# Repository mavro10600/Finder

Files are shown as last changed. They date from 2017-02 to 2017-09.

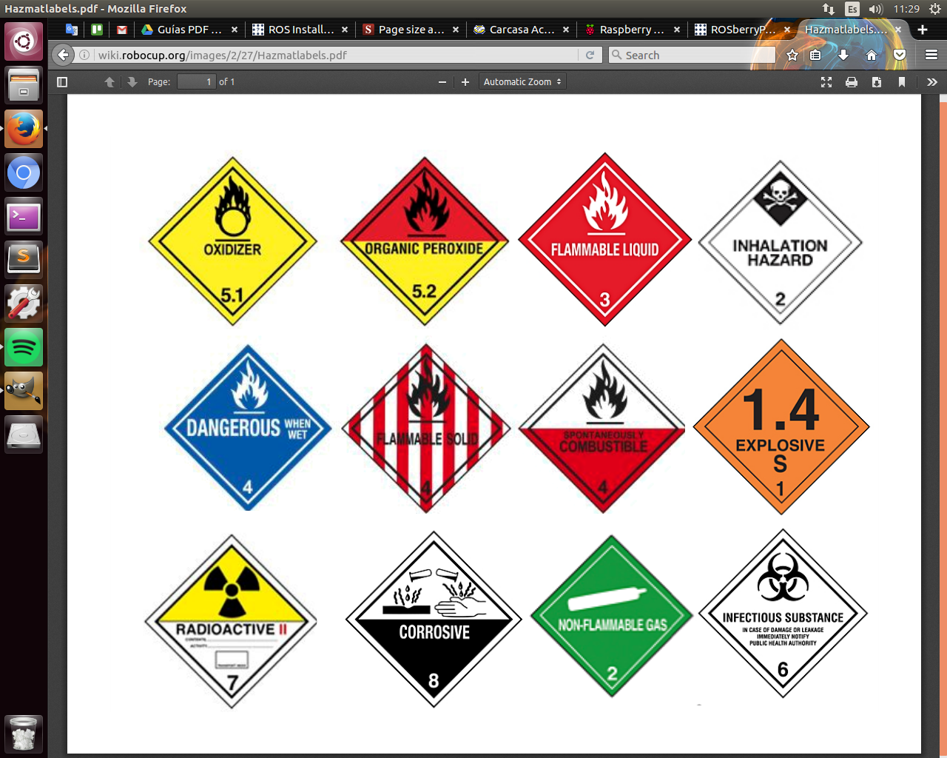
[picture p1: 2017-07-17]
catkin_et/src/vision/labels_hazmate_detector/scripts/hlabel/hazard_labels.png

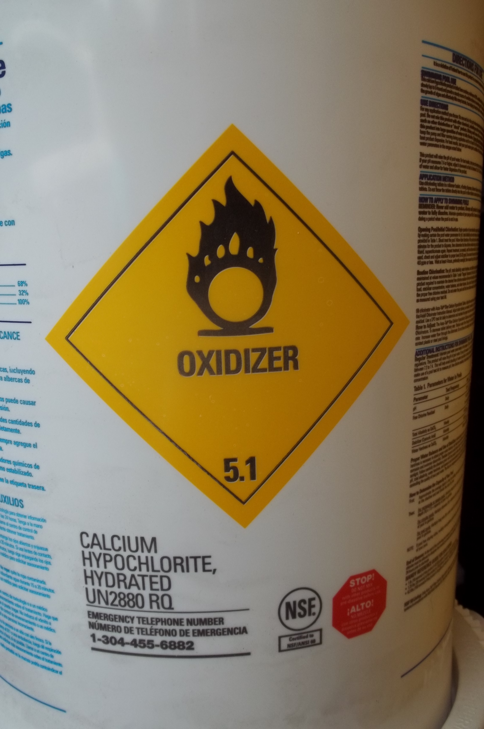
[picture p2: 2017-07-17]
catkin_et/src/vision/labels_hazmate_detector/scripts/hlabel/oxidizerTest1.jpg

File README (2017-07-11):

//
//readme de mavro
//hola
//procedimiento para usar el workspace de ROS:
Primero, en la carpeta build, en el archivo Makefile
cambiamos la ruta de source dir y de binary dir

# The top-level source directory on which CMake was run.
CMAKE_SOURCE_DIR = /home/mavro/Finder/Finder/catkin_et/src

# The top-level build directory on which CMake was run.
CMAKE_BINARY_DIR = /home/mavro/Finder/Finder/catkin_et/build

Luego, vamos a la carpeta catkin_et, y ejecutamos el comando:

$ catkin_make -DCMAKE_BUILD_TYPE=Release

Luego 

$ source ./devel/setup.bash
finder@finder-Dell-System-XPS-15Z:~ .->rosparam set /order "[ 1,2,3,4]"
finder@finder-Dell-System-XPS-15Z:~ .->rosparam set /sentido "[1,0,0,0]"

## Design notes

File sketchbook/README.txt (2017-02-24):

Veamos, faltaaa
Unir los codigos de aqui usando rosserial
entonces, primero usar rosserial para enviar un dato tipo tf, 
luego en la compu
mandar un nodo que lea lo que publica en esa direccion serial el arduino
y lu publique a un jointstate
Entonces lo va  a leer este otro nodo que va a hacer algo con el digamos 
convertirlo a radianes o ago asi
El archivo Position1 Motor test es el mas actual, digamos, en el es con 
arduino mega y veamos, si se utiliza con rosserial para enviar el estado
de la junta, veamos entonces eso es lo que quiero lograr.

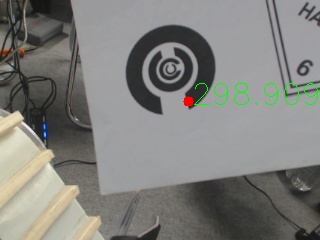
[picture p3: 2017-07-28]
catkin_et/src/roswww/www/img/temp/cPatternDetected5.21694941916.jpg

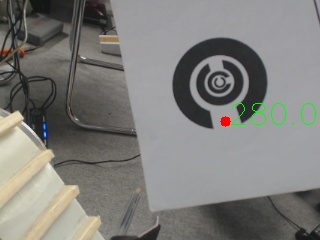
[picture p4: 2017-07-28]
catkin_et/src/roswww/www/img/temp/cPatternDetected4.88778320093.jpg

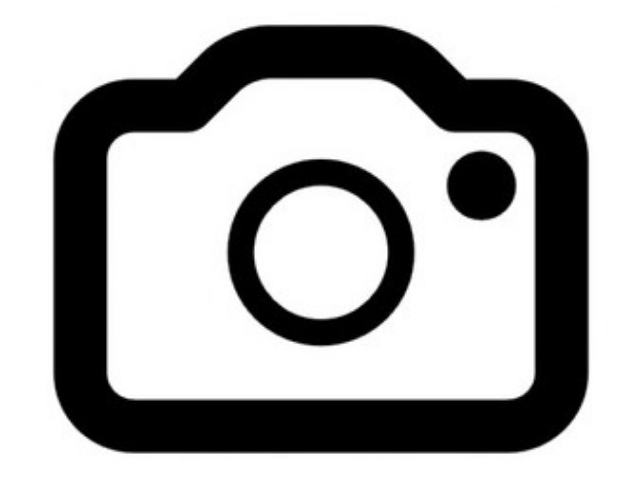
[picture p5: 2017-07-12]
catkin_et/src/roswww/www/img/camera.jpg

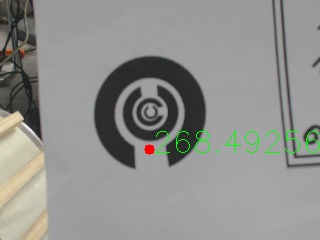
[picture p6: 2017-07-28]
catkin_et/src/roswww/www/img/temp/cPatternDetected4.68607926313.jpg

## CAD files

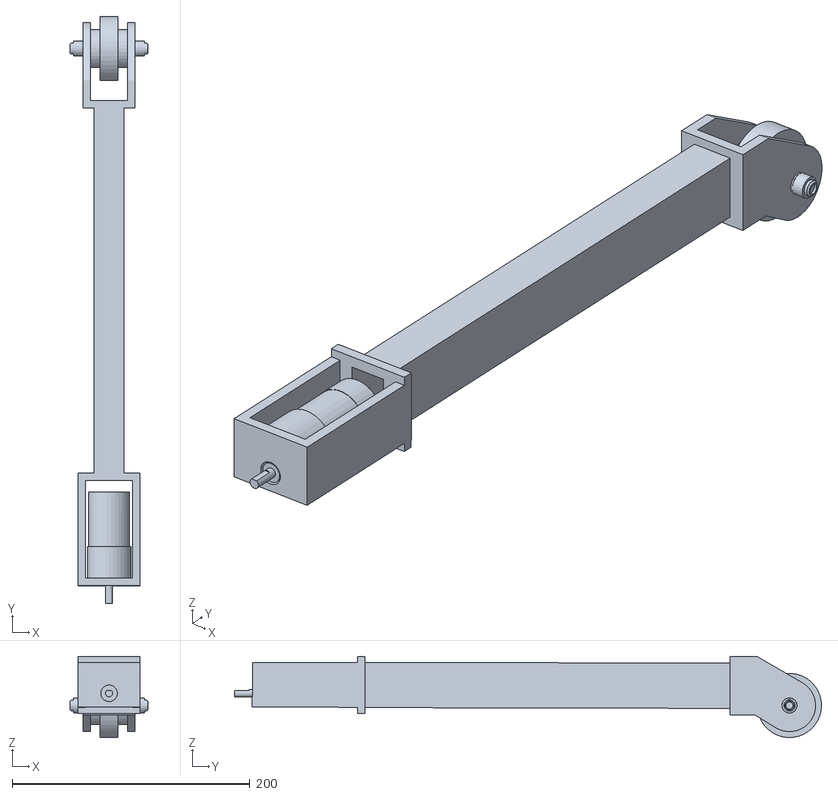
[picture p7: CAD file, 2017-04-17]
catkin_et/src/config_files/meshes/codo.stl
65.7 x 494.1 x 68.3

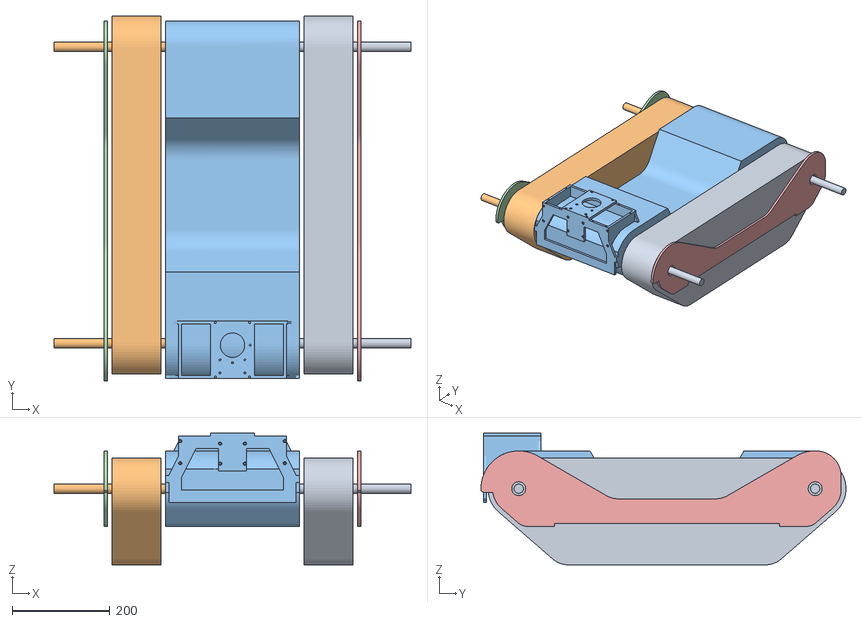
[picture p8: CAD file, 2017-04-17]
catkin_et/src/finder_description/chasis.obj
727.8 x 745.0 x 269.1

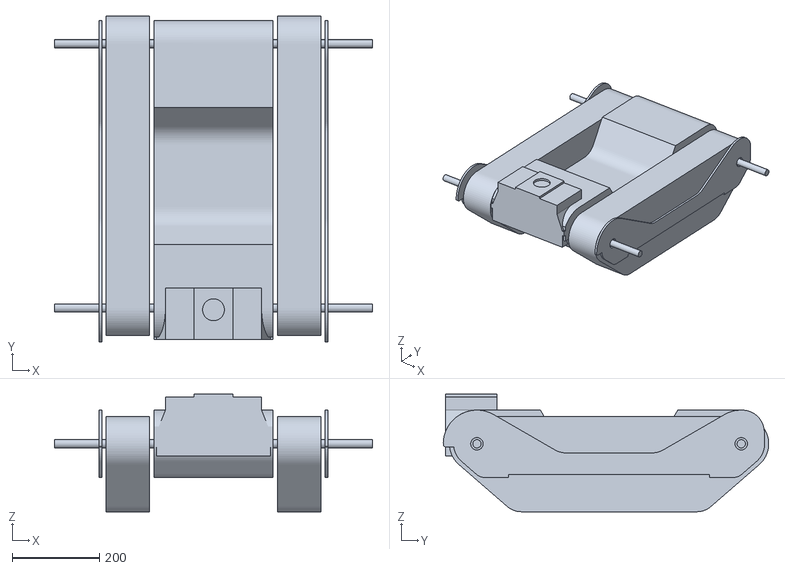
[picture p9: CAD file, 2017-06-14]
catkin_et/src/finder_description/mallas/chasis.stl
727.8 x 745.0 x 269.1

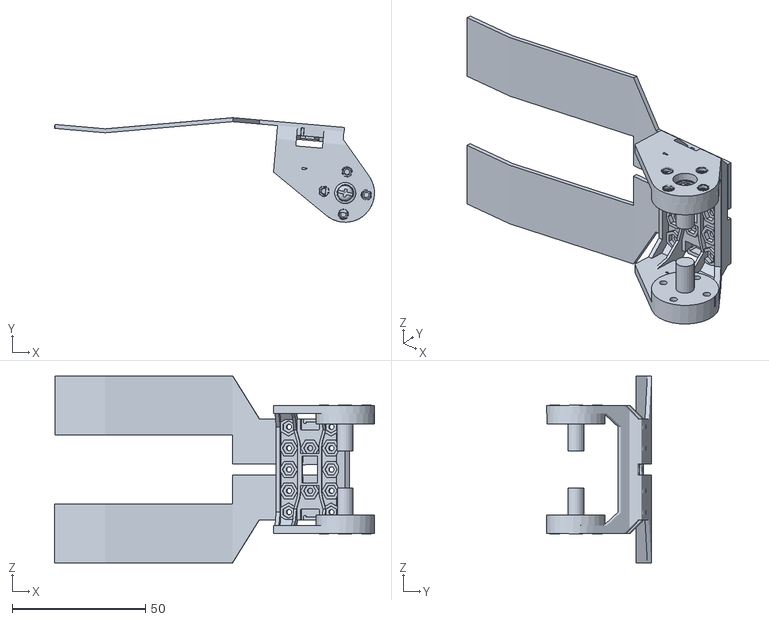
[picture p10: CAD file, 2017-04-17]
catkin_et/src/finder_description/meshes/fingers_finder_arm_l.obj
120.1 x 39.3 x 70.0

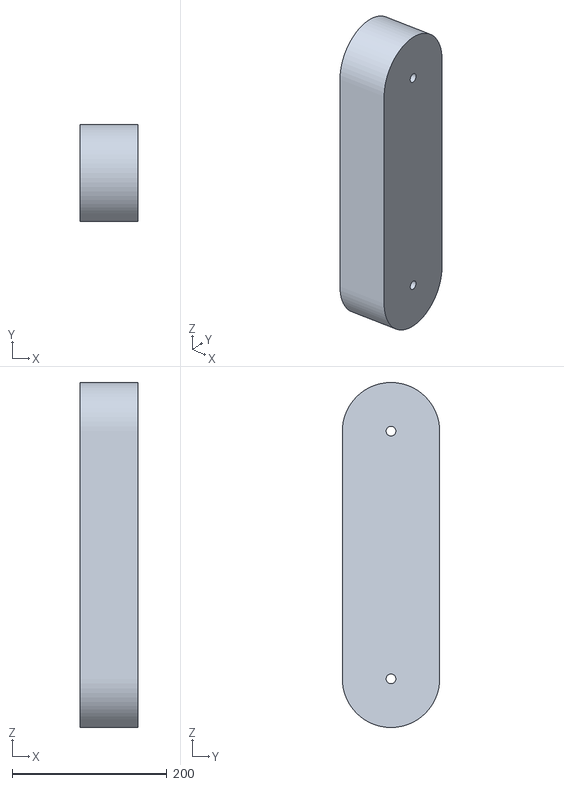
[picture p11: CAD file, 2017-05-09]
catkin_et/src/finder_description/meshes_light/brazo_izq_trasero.stl
75.0 x 125.9 x 445.9

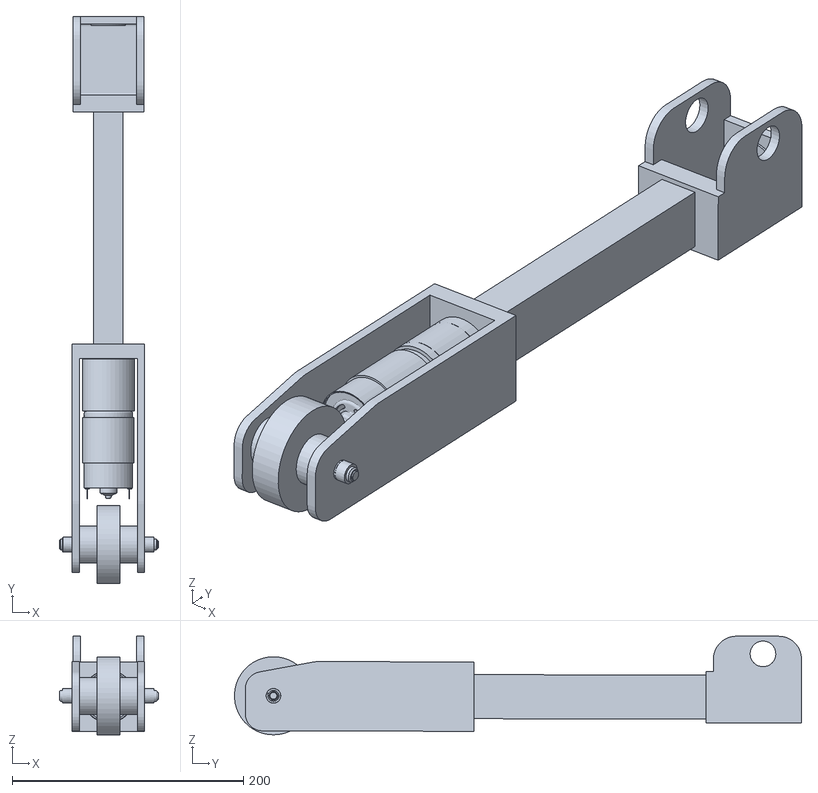
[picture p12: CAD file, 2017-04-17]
catkin_et/src/config_files/meshes/hombro.stl
85.7 x 490.0 x 85.3

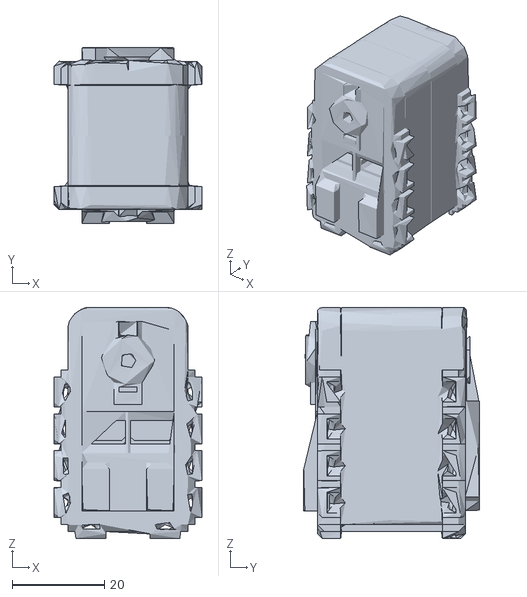
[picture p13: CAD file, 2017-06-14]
catkin_et/src/finder_description/mallas/ax12_box.stl
32.0 x 38.0 x 50.0

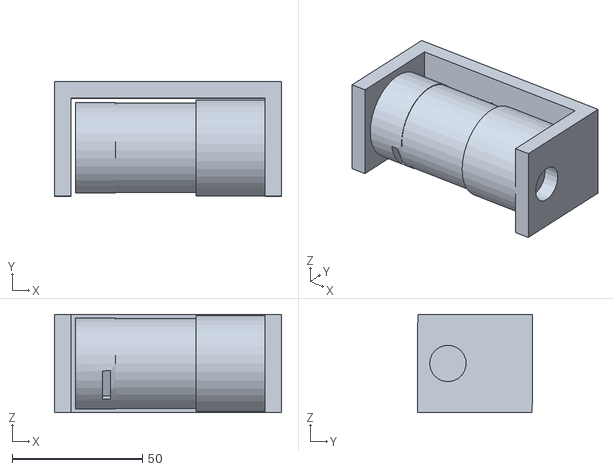
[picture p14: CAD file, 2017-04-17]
catkin_et/src/finder_description/meshes_2/roll1.obj
87.0 x 44.0 x 37.7

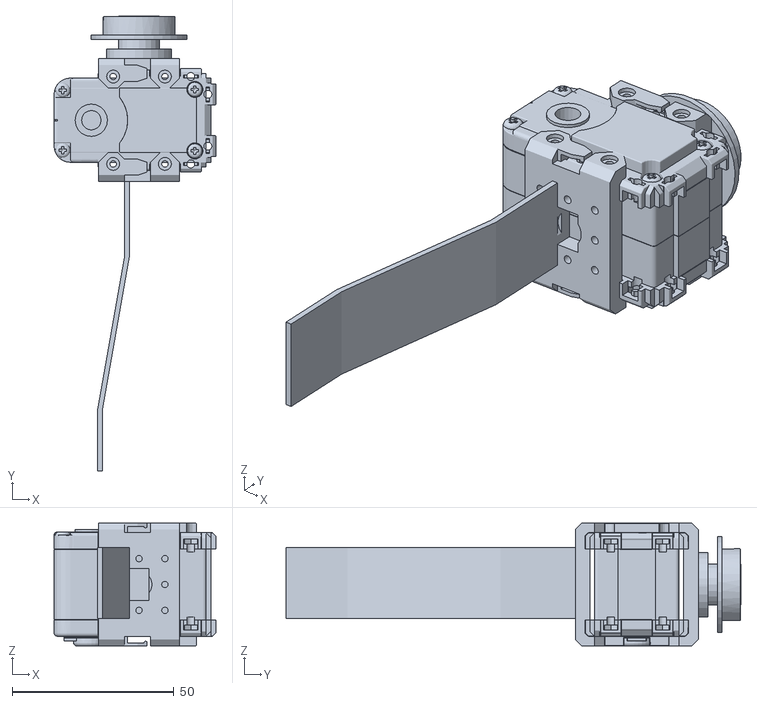
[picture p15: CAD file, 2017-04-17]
catkin_et/src/config_files/meshes/yaw_finder_arm_.obj
50.0 x 140.6 x 38.0

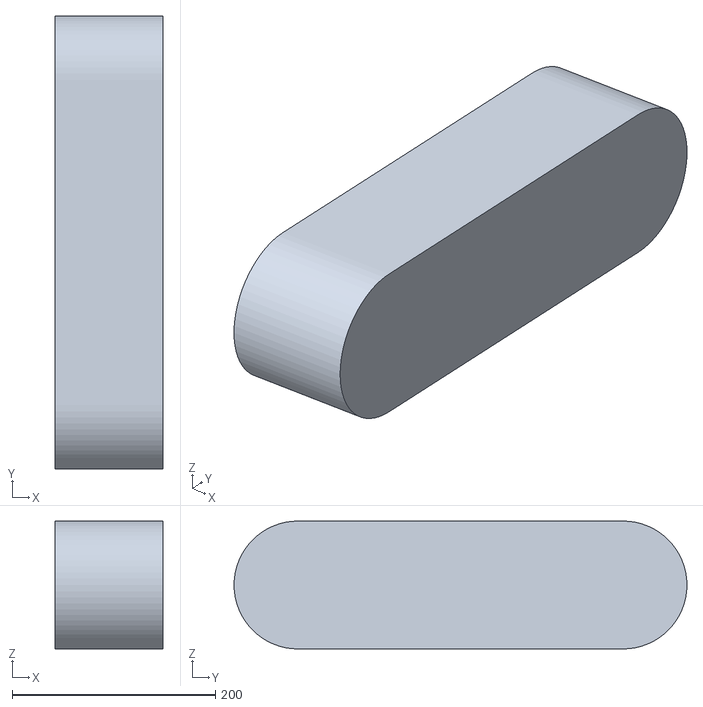
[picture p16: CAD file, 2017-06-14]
catkin_et/src/finder_description/mallas/brazo_auxiliar_simple.stl
106.6 x 445.9 x 125.9

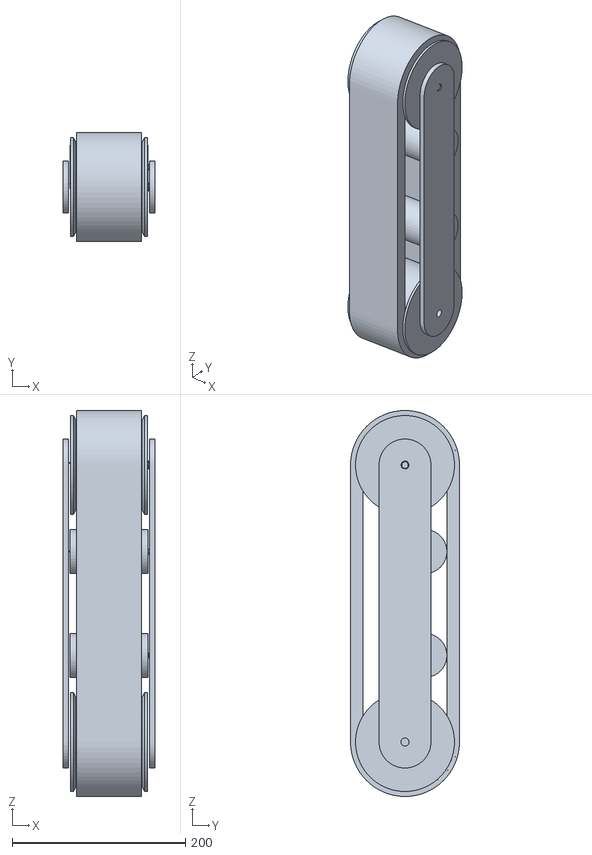
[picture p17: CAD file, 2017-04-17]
catkin_et/src/finder_description/meshes_2/flipper_lb.obj
106.6 x 125.9 x 445.9

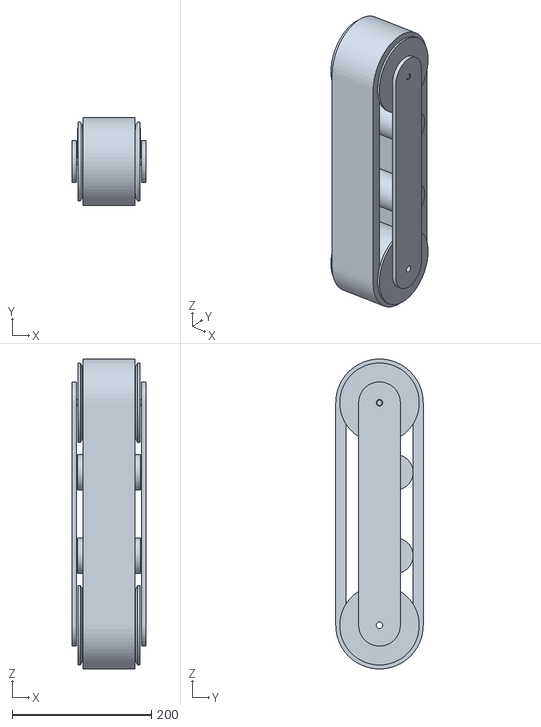
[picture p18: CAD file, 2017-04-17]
catkin_et/src/config_files/meshes/brazo_der_trasero_v2.stl
106.6 x 125.9 x 445.9

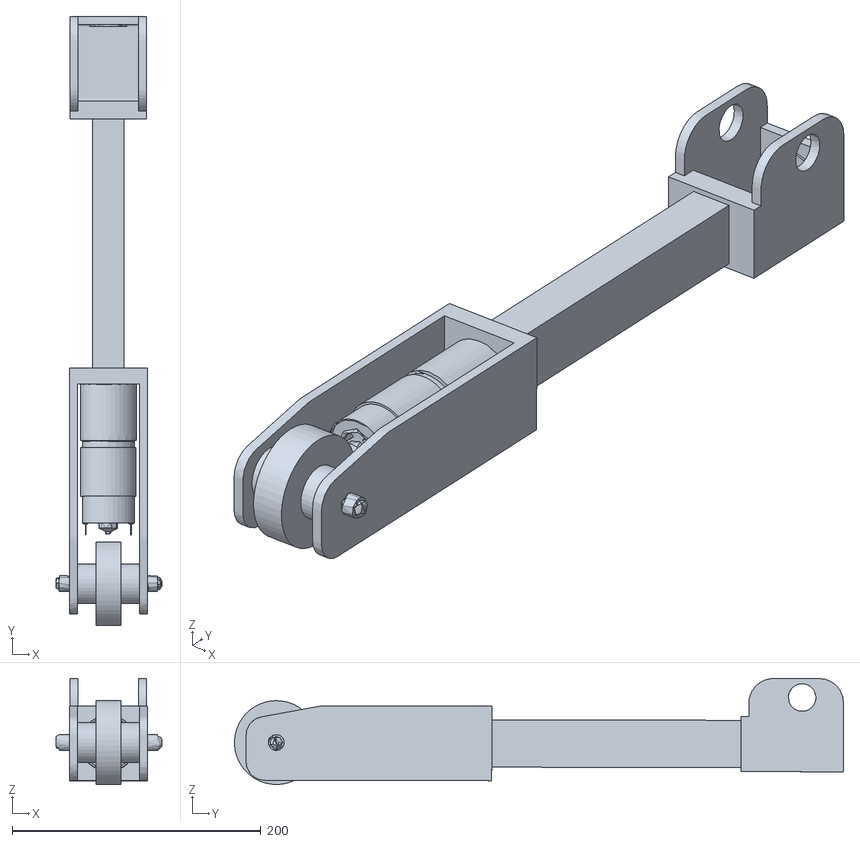
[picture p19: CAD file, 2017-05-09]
catkin_et/src/finder_description/mallas/hombro.obj
85.6 x 490.0 x 85.3

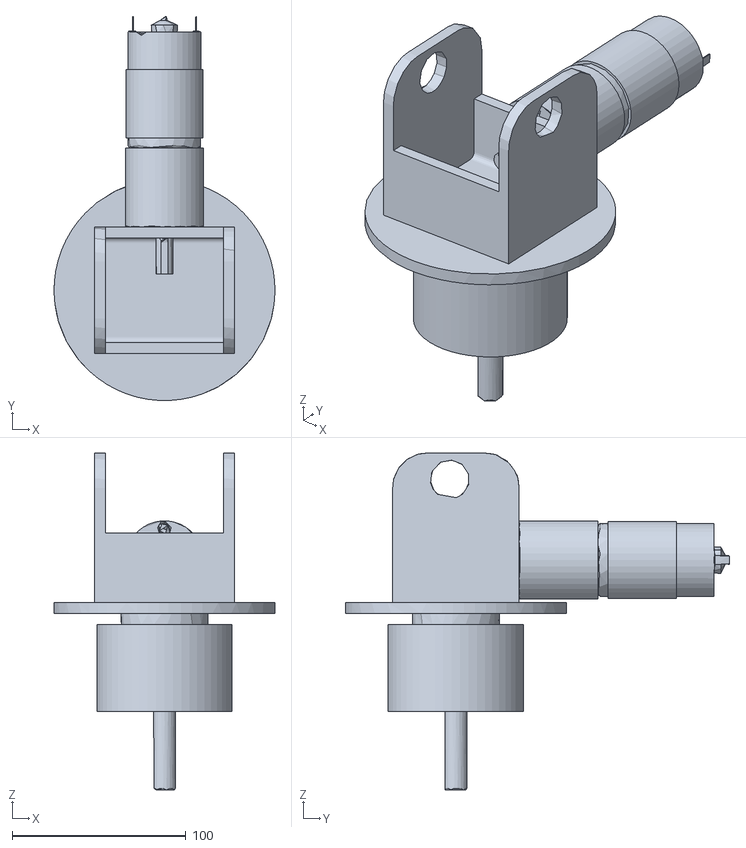
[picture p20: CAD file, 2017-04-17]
catkin_et/src/finder_description/meshes_2/base.obj
127.0 x 220.8 x 193.7

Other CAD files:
catkin_et/src/finder_description/meshes_2/fingers.obj
catkin_et/src/finder_description/meshes_light/brazo_der_frontal.stl
catkin_et/src/finder_description/meshes_light/brazo_der_trasero.stl
catkin_et/src/finder_description/meshes_light/brazo_izq_frontal.stl
catkin_et/src/config_files/meshes/base.obj
catkin_et/src/config_files/meshes/base.stl
catkin_et/src/config_files/meshes/brazo_der_frontal_v2.obj
catkin_et/src/config_files/meshes/brazo_der_frontal_v2.stl
catkin_et/src/config_files/meshes/brazo_der_trasero_v2.obj
catkin_et/src/config_files/meshes/brazo_izq_frontal_v2.obj
catkin_et/src/config_files/meshes/brazo_izq_frontal_v2.stl
catkin_et/src/config_files/meshes/brazo_izq_trasero_v2.obj
catkin_et/src/config_files/meshes/brazo_izq_trasero_v2.stl
catkin_et/src/config_files/meshes/chasis.obj
catkin_et/src/config_files/meshes/codo.obj
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

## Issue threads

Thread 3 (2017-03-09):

Como usar con ros el programa prueba roboclaw 1tarjeta

mavro10600, 2017-03-09:
Bien,  primero que nada, me parece que esta funcionando para roll y pitch. El objeto asociado es rc,conectado al serial3 de la stellaris, la velocidad de comunicación creo que esta en 115200,  si su roboclaw no esta a esa velocidad no va a pasar nada,  si presionas mode y parpadea creo 8 veces es que esta en packet serial y el address es 80, presionas lipo un par de segundos y sales,  luego presionas set y si parpadea 4veces la velocidad es de 38400,presinas dos veces set para avanzar a 115200,  el caso es que parpadee 6 veces.  Conectas s1 y s2 a pd6 y pd7 me parece,si no los volteas,  descubrí que el conversor de niveles no es necesario.  Y luego,  en tu laptop,  lanzas roscore y luego rosrun rosserial-python serial_node. Py /dev/ttyACM0, o puedes laanzar mas explicito como argumentos_port:=/dev/ttyACM0_baud:=57600 o algo asi,  no recuerdo bien al valor del baudaje.
Y mmm si lanzas rostopic list deben aparecer los topicos que lanza y recibe la stellaris, shoulder_out y shoulder por ejemplo,  el primero es el valor a enviar para controlar el motoor del hombro y shoukder es el valor del encoder asociado.  Puedes escribir rostopic echo /shoulder oara ver el valor del encoder,  y rostopic pub /shoulder_out std_msgs/Int16 70 para mandar que se mueva el motor.  Entonces,  en el codigo de la stellaris,  tienes el objeto rc,  asociado a la rovoclaw conectada a los pines del serial3,  en la función setup encoders llamamos la instrucción setencodermode y el argumento es 0 para que funcione como encoder de cuadratura,  si enviamos un 129 funciona como encoder analógica.  Luego en la funcion update motors,  llamo la funcion rc. forwardbackwardM1 (address, roll_out)  donde 64 es paro,  0 es toda la velocidad. Hacia un lado y 128 para el otro lado,  asi qie lo que publiques al topico en ros desde tu lap,  procura que este entre esos valores,  asimismo en el programa,  inicio en valor de roll_ouyt=64

Closed 2017-05-02.

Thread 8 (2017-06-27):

Subir codigo de la stellaris de sensores

mavro10600, 2017-06-27:
Cesar, sube el codigo de tu stellaris y agrega pines para que lean los sensores de corriente, tambien juntar el codigo de eli para controlar los leds de potencia y el termografo

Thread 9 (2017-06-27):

hacer rutina de finales de carrera

mavro10600, 2017-06-27:
hacer pines de finles de carrera y el nodo de begginers tutorials/ scripts/base_launchpad.py para que reconozca un Reset enviado por la stellaris. asimismo en le programa de brazo stellaris launchpad poner la rutina que apague el motor y envie cero en dicho motor asi como el mensaje de status de finales de carrera

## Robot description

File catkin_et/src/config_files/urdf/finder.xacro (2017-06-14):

<?xml version="1.0"?>
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
<robot name="finder" xmlns:xacro="http://www.ros.org/wiki/xacro">

	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
    <xacro:macro name="default_geometry" params="cad_dir:=package://config_files/meshes cad_file extension:=obj">
        <geometry>
	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
        </geometry>
    </xacro:macro>

	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
	<xacro:property name="pi" value = "3.14159265359"/>
	<property name="deg_to_rad" value="0.01745329251994329577"/>

	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
   	<xacro:macro name="inertial_matrix" params="mass">
    	<inertial>
      		<mass value="${mass}"/>
        	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
  		</inertial>
   </xacro:macro>

	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
	<xacro:macro name = "lateral_arms" params="name cad_name origin">
		<link name = "${name}">
			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
	</link>
	</xacro:macro>
	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
	<xacro:macro name = "arms_joints" params="name child origin">
		<joint name = "${name}" type="revolute">
			<parent link = "base_link"/>
			<child link = "${child}"/>
			<origin xyz ="${origin}"/>
			<axis xyz = "1 0 0"/>
			<limit effort="300" velocity="0.1" lower="${-pi}" upper="${pi}"/>
		</joint>
	</xacro:macro>

	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
	<property name="shoulder_coll_len" value="0.456" />
	<property name="shoulder_coll_width" value="0.062" />
	<property name="shoulder_coll_height" value="0.05" />
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
	<property name="elbow_coll_len" value="0.393" />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
	<property name="elbow_coll_width" value="0.052" />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
	<property name="elbow_coll_height" value="0.0475" />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
	<property name="roll_coll_len" value="0.05"/>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
	<property name="roll_coll_width" value="0.087" />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
	<property name="roll_coll_height" value="0.03" />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
	<property name="cylinder_len" value ="0.087"/>
	<property name="cylinder_rad" value ="0.0187"/>

	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
	<property name="grasp_frame_len" value="0.02"/>
	<property name="grasp_frame_width" value="0.02"/>
	<property name="grasp_frame_height" value="0.02"/>
	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
	<link name = "base_link">
		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
	</link>
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
	<xacro:arms_joints name="right_front_flipper" child="right_front_arm" origin="-0.3264 -0.30255 0.1556"/>

	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
	<xacro:arms_joints name="left_front_flipper" child="left_front_arm" origin="0.3264 -0.30255 0.1556"/>

	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
	<xacro:arms_joints name="right_back_flipper" child="right_back_arm" origin="-0.3264 0.30255 0.1556"/>

	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
	<xacro:arms_joints name="left_back_flipper" child="left_back_arm" origin="0.3264 0.30255 0.1556"/>

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
	<xacro:lateral_arms name="right_front_arm" cad_name="brazo_der_frontal_v2" origin="0.3264 0.30255 -0.0629"/>

	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
	<xacro:lateral_arms name="left_front_arm" cad_name="brazo_izq_frontal_v2" origin="-0.3264 0.30255 -0.0629"/>

	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
	<xacro:lateral_arms name="right_back_arm" cad_name="brazo_der_trasero_v2" origin="0.3264 -0.30255 -0.0629"/>

	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
	<xacro:lateral_arms name="left_back_arm" cad_name="brazo_izq_trasero_v2" origin="-0.3264 -0.30255 -0.0629"/>

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
	<joint name = "base_rotation" type="revolute">
		<parent link = "base_link"/>
		<child link = "eje_tronco"/>
		<origin xyz ="0 -0.30645 ${0.2691-0.0455}" rpy="0 0 0"/>
		<axis xyz = "0 0 1"/>
		<limit effort="300" velocity="0.1" lower="${-pi}" upper="${pi}"/>
	</joint>

	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
	<link name = "eje_tronco">
		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
	</link>
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
	<joint name = "shoulder_rotation" type = "revolute">
		<parent link = "eje_tronco"/>
		<child link = "shoulder"/>
		<origin xyz = "0 -0.0035 0.179"/>
		<axis xyz = "1 0 0"/>
		<limit effort="300" velocity="0.1" lower="${-pi}" upper="${pi}"/>
	</joint>
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
	<link name = "shoulder">
		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
	</link>
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
	<joint name = "elbow_rotation" type = "revolute">
		<parent link = "shoulder"/>
		<child link = "elbow"/>
		<origin xyz = "0 0.423 0.0363"/>
		<axis xyz = "1 0 0"/>
		<limit effort="300" velocity="0.1" lower="${-pi}" upper="${pi}"/>
	</joint>

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
	<link name = "elbow">
		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
	</link>
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
	<joint name = "roll_rotation" type = "revolute">
		<parent link = "elbow"/>
		<child link = "roll"/>
		<origin xyz = "0 -0.4192 0.0103"/>
		<axis xyz = "0 1 0"/>
		<limit effort="300" velocity="0.1" lower="${-pi}" upper="${pi}"/>
	</joint>

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
	<link name = "roll">
		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
	</link>
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
	<joint name = "pitch_rotation" type = "revolute">
		<parent link = "roll"/>
		<child link = "pitch"/>
		<origin xyz = "0 -0.0778 0"/>
		<axis xyz = "1 0 0"/>
		<limit effort="300" velocity="0.1" lower="${-pi}" upper="${pi}"/>
	</joint>
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
	<link name = "pitch">
		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
	</link>
	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
	<joint name = "roll_rotation_2" type = "revolute">
		<parent link = "pitch"/>
		<child link = "yaw"/>
		<origin xyz = "0 -0.0835 0"/>
		<axis xyz = "0 1 0"/>
		<limit effort="300" velocity="0.1" lower="${-pi}" upper="${pi}"/>
	</joint>
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
	<link name = "yaw">
		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
	</link>
	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
	<joint name = "gripper_rotation" type = "revolute">
		<parent link = "yaw"/>
		<child link = "gripper"/>
		<origin xyz = "-0.0147485 -0.003042 0"/>
		<axis xyz = "0 0 1"/>
		<limit effort="300" velocity="0.1" lower="${-pi}" upper="${pi}"/>
	</joint>
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
	<link name = "gripper">
		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
	</link>
	
    <link name="grasping_frame">
      	<inertial>
        	<origin xyz="0 0 0" rpy="0 0 0"/>
        	<mass value="0.001"/>
        	<cuboid_inertia mass="0.0001" x="0.001" y="0.001" z="0.001"/>
        	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
      	</inertial>
		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
    </link>
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
    <joint name="grasping_frame_joint" type="fixed">
      <parent link="yaw"/>
      <child link="grasping_frame"/>
      <origin xyz="-0.023 -0.1 0"/>
    </joint>
</robot>

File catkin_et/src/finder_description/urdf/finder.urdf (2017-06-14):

<?xml version="1.0" ?>
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
<robot name="finder" xmlns:xacro="http://www.ros.org/wiki/xacro">
  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
  <link name="base_link">
    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
  </link>
  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
  <joint name="right_front_flipper" type="revolute">
    <parent link="base_link"/>
    <child link="right_front_arm"/>
    <origin xyz="-0.3264 -0.30255 0.1556"/>
    <axis xyz="1 0 0"/>
    <limit effort="300" lower="-3.14159265359" upper="3.14159265359" velocity="0.1"/>
  </joint>
  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
  <joint name="left_front_flipper" type="revolute">
    <parent link="base_link"/>
    <child link="left_front_arm"/>
    <origin xyz="0.3264 -0.30255 0.1556"/>
    <axis xyz="1 0 0"/>
    <limit effort="300" lower="-3.14159265359" upper="3.14159265359" velocity="0.1"/>
  </joint>
  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
  <joint name="right_back_flipper" type="revolute">
    <parent link="base_link"/>
    <child link="right_back_arm"/>
    <origin xyz="-0.3264 0.30255 0.1556"/>
    <axis xyz="1 0 0"/>
    <limit effort="300" lower="-3.14159265359" upper="3.14159265359" velocity="0.1"/>
  </joint>
  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
  <joint name="left_back_flipper" type="revolute">
    <parent link="base_link"/>
    <child link="left_back_arm"/>
    <origin xyz="0.3264 0.30255 0.1556"/>
    <axis xyz="1 0 0"/>
    <limit effort="300" lower="-3.14159265359" upper="3.14159265359" velocity="0.1"/>
  </joint>
  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
  <link name="right_front_arm">
    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
  </link>
  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
  <link name="left_front_arm">
    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
  </link>
  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
  <link name="right_back_arm">
    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
  </link>
  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
  <link name="left_back_arm">
    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
  </link>
  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
  <joint name="base_rotation" type="revolute">
    <parent link="base_link"/>
    <child link="eje_tronco"/>
    <origin rpy="0 0 0" xyz="0 -0.30645 0.2236"/>
    <axis xyz="0 0 1"/>
    <limit effort="300" lower="-3.14159265359" upper="3.14159265359" velocity="0.1"/>
  </joint>
  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
  <link name="eje_tronco">
    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
  </link>
  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
  <joint name="shoulder_rotation" type="revolute">
    <parent link="eje_tronco"/>
    <child link="shoulder"/>
    <origin xyz="0 -0.0035 0.179"/>
    <axis xyz="1 0 0"/>
    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
    <limit effort="300" lower="0" upper="3.1" velocity="0.1"/>
  </joint>
  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
  <link name="shoulder">
    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
  </link>
  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
  <joint name="elbow_rotation" type="revolute">
    <parent link="shoulder"/>
    <child link="elbow"/>
    <origin xyz="0 0.423 0.0363"/>
    <axis xyz="1 0 0"/>
    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
    <limit effort="300" lower="-2.3" upper="0" velocity="0.1"/>
  </joint>
  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
  <link name="elbow">
    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
  </link>
  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
  <joint name="roll_rotation" type="revolute">
    <parent link="elbow"/>
    <child link="roll"/>
    <origin xyz="0 -0.4192 0.0103"/>
    <axis xyz="0 1 0"/>
    <limit effort="300" lower="-3.14159265359" upper="3.14159265359" velocity="0.1"/>
  </joint>
  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
  <link name="roll">
    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
  </link>
  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
  <joint name="pitch_rotation" type="revolute">
    <parent link="roll"/>
    <child link="pitch"/>
    <origin xyz="0 -0.0778 0"/>
    <axis xyz="1 0 0"/>
    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
    <limit effort="300" lower="-1.0471975512" upper="1.0471975512" velocity="0.1"/>
  </joint>
  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
  <link name="pitch">
    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
  </link>
  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
  <joint name="roll_rotation_2" type="revolute">
    <parent link="pitch"/>
    <child link="yaw"/>
    <origin xyz="0 -0.0835 0"/>
    <axis xyz="0 1 0"/>
    <limit effort="300" lower="-3.14159265359" upper="3.14159265359" velocity="0.1"/>
  </joint>
  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
  <link name="yaw">
    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
  </link>
  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
  <joint name="gripper_rotation" type="revolute">
    <parent link="yaw"/>
    <child link="gripper"/>
    <origin xyz="-0.0147485 -0.003042 0"/>
    <axis xyz="0 0 1"/>
    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
    <limit effort="300" lower="0" upper="3.14159265359" velocity="0.1"/>
  </joint>
  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
  <link name="gripper">
    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
  </link>
  <link name="grasping_frame">
    <inertial>
      <origin rpy="0 0 0" xyz="0 0 0"/>
      <mass value="0.001"/>
      <cuboid_inertia mass="0.0001" x="0.001" y="0.001" z="0.001"/>
      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
    </inertial>
    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
  </link>
  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
  <joint name="grasping_frame_joint" type="fixed">
    <parent link="yaw"/>
    <child link="grasping_frame"/>
    <origin xyz="-0.023 -0.1 0"/>
  </joint>
</robot>

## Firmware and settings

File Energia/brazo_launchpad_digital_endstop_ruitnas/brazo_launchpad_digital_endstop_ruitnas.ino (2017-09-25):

#include <Messenger.h>
#include <limits.h>
#include "RoboClaw.h"


#include <Servo.h>
#include "DynamixelSerial.h"
#include "SimpleDynamixel.h"
#include "Talon.h"
#include "SimpleServo.h"
#include "AS5043.h"
#include "Encoder.h"

////*
/*
 * TODO agregar dynamixel
 * 
 * revisar funcionamiento de sensores
 * 
 * uint16_t ReadMainBatteryVoltage(uint8_t address,bool *valid=NULL);
 * 
 * 
 * 
 * 
 * 
 */

#define pinCytronDir PD_2
#define pinCytronPwm PD_1

#define pindo1 PE_3
#define pinclk1 PE_1
#define pincsn1 PE_2 

#define pindo2 PC_4
#define pinclk2 PB_3
#define pincsn2 PC_5 

#define pindo3 PA_4
#define pinclk3 PA_3
#define pincsn3 PA_2 

//Definimos los pines de los finales de carrera
#define pinendstopBase1 PB_5
#define pinendstopBase2 PB_0
#define pinendstopShoulder1 PB_1
#define pinendstopShoulder2 PE_4
#define pinendstopElbow1 PE_5
#define pinendstopElbow2 PB_4
#define pinendstopRoll1 PA_5
#define pinendstopRoll2 PA_6
#define pinendstopPitch1 PA_7
#define pinendstopPitch2 PF_1
#define pinendstopYaw1 PE_0
#define pinendstopYaw2 PF_0


Servo wrist_servo;
Servo base;
//umbral,max
TalonClass BASE(2,50);

  /*EncoderClass(int anPin, int min, int max, int maxChange, int map_out);  
   * The basic constructor types specify:
   *
   * anPIn - if the sensor is pure analog, use this pin for analogRead
   * AS5043 - if the sensor is MGN ABS 10 BIT in SPI (hardware or software) mode read, use this object to perform read
   * indexChain - The "number" of the sensor in the "chain". Use 0 if there is a single sensor per CS pin, at most MAX_DEVICES - 1  (currently 3)
   * pinCSn - Serves to specify an CS pin to perform read, in case one is needed for this encoder
   *
   * min - minimal value of lecture, if not specified then 0
   * max - maximal value of lecture, if not specified then 1023
   * map_out - if > 0, use INCREASING values, if < 0, use DECREASING values, if 0 report lecture
   *       the magnitude of map_out is used to specify "output angle" size. This is, if magnitude is 127, read goes from -127 to +127,
   *       if magnitude is 511, read goes from -511 to +511, etc.
   *
   */
Messenger Messenger_Handler=Messenger();
//reset pin for tiva , if this pin set HIGH, will reset
#define RESET_PIN PB_2


////////////////////////////
//Time update variables

unsigned long LastUpdateMicrosecs=0;
unsigned long LastUpdateMillisecs=0;
unsigned long CurrentMicrosecs=0;
unsigned long MicrosecsSinceLastUpdate=0;
float SecondsSinceLastUpdate=0;


///////////////////////////////////////////////////////////////////
//Variables de los encoders
int stat_complete=0;

int vueltas1;
unsigned int last_lec1;
boolean stat1;


int vueltas2;
unsigned int last_lec2;
boolean stat2;

int vueltas3;
unsigned int last_lec3;
boolean stat3;

///banderas endstops
boolean base_stat;

boolean shoulder_stat;

boolean elbow_stat;

boolean roll_stat;

boolean pitch_stat;

boolean yaw_stat;



//BANDERAS DE FINALES DE CARRERA
bool flagEndstopBase1;
bool flagEndstopBase1prev;
bool flagEndstopBase2;
bool flagEndstopBase2prev;
bool flagEndstopShoulder1;
bool flagEndstopShoulder1prev;
bool flagEndstopShoulder2;
bool flagEndstopShoulder2prev;
bool flagEndstopElbow1;
bool flagEndstopElbow1prev;
bool flagEndstopElbow2;
bool flagEndstopElbow2prev;
bool flagEndstopRoll1;
bool flagEndstopRoll1prev;
bool flagEndstopRoll2;
bool flagEndstopRoll2prev;
bool flagEndstopPitch1;
bool flagEndstopPitch1prev;
bool flagEndstopPitch2;
bool flagEndstopPitch2prev;
bool flagEndstopYaw1;
bool flagEndstopYaw1prev;
bool flagEndstopYaw2;
bool flagEndstopYaw2prev;

////////////////////////////////////////////////////////////////////////////////////////////////////////////////////
///In fromROS

int base_out=1500;
int shoulder_out=64;
int elbow_out=64;
int roll_out= 64;
int pitch_out = 64;
int yaw_out = 64;
int gripper_out = 64;

int basel=0;
int shoulder=0;
int elbow=0;
int roll=0;
int pitch=0;
int yaw=0;
int gripper=0;

int battery=12;

///////////////////////////////////////
//Motor speed

//Velocity PID coefficients
#define Kp 70.0
#define Ki 0
#define Kd 0
#define qpps 44000
  uint32_t kiMax=0;
  uint32_t deadzone=5;
  uint32_t mini=100;
  uint32_t maxi=700;  


//Uncomment if Using Hardware Serial port
RoboClaw roboclaw(&Serial2,10000);
RoboClaw rc(&Serial3,10000);

#define address 0x80

void setup() {
  //Open Serial and roboclaw serial ports
  Serial.begin(115200);//cuando se ve en el ide de arduino

  roboclaw.begin(38400);
  
  rc.begin(38400);
  
  SetupEncoders();
  
  SetupMotors();
  
  SetupReset();

  Messenger_Handler.attach(OnMssageCompleted);

  SetupEndstop();
}

void SetupEncoders()
{
pinMode(pinclk1,OUTPUT);
pinMode(pindo1,INPUT);
pinMode(pincsn1,OUTPUT);
digitalWrite(pincsn1,HIGH);
digitalWrite(pinclk1, HIGH);  
delay(100);
pinMode(pinclk2,OUTPUT);
pinMode(pindo2,INPUT);
pinMode(pincsn2,OUTPUT);
digitalWrite(pincsn2,HIGH);
digitalWrite(pinclk2, HIGH);  
delay(100);
pinMode(pinclk3,OUTPUT);
pinMode(pindo3,INPUT);
pinMode(pincsn3,OUTPUT);
digitalWrite(pincsn3,HIGH);
digitalWrite(pinclk3, HIGH);  
delay(100);
  ///Encoders de cuadratura
}

void SetupMotors()
{
  ///Aqui configuramos el tipo de control
  //Set PID Coefficients
  wrist_servo.attach(PE_1);
  base.attach(PD_3);
  pinMode(pinCytronPwm,OUTPUT);
  pinMode(pinCytronDir,OUTPUT);
  digitalWrite(pinCytronDir,LOW);
  digitalWrite(pinCytronPwm,LOW);
}

void SetupReset()
{
  pinMode(GREEN_LED,OUTPUT);
  pinMode(RESET_PIN,OUTPUT);

  ///Conectar el pin de reset al pin reset de la placa
  digitalWrite(RESET_PIN,HIGH);
}

void SetupEndstop(){
  pinMode(pinendstopBase1,INPUT_PULLUP);
  attachInterrupt(pinendstopBase1,ISRendBase1,CHANGE);
  
  pinMode(pinendstopBase2,INPUT_PULLUP);
  attachInterrupt(pinendstopBase2,ISRendBase2,CHANGE);
  
  pinMode(pinendstopShoulder1,INPUT_PULLUP);
  attachInterrupt(pinendstopShoulder1,ISRendShoulder1,CHANGE);
  
  pinMode(pinendstopShoulder2,INPUT_PULLUP);
  attachInterrupt(pinendstopShoulder2,ISRendShoulder2,CHANGE);
  
  pinMode(pinendstopElbow1,INPUT_PULLUP);
  attachInterrupt(pinendstopElbow1,ISRendElbow1,CHANGE);
  
  pinMode(pinendstopElbow2,INPUT_PULLUP);
  attachInterrupt(pinendstopElbow2,ISRendElbow2,CHANGE);
  
  pinMode(pinendstopRoll1,INPUT_PULLUP);
  attachInterrupt(pinendstopRoll1,ISRendRoll1,CHANGE);
  
  pinMode(pinendstopRoll2,INPUT_PULLUP);
  attachInterrupt(pinendstopRoll2,ISRendRoll2,CHANGE);
  
  pinMode(pinendstopPitch1,INPUT_PULLUP);
  attachInterrupt(pinendstopPitch1,ISRendPitch1,CHANGE);
  
  pinMode(pinendstopPitch2,INPUT_PULLUP);
  attachInterrupt(pinendstopPitch2,ISRendPitch2,CHANGE);
  
  pinMode(pinendstopYaw1,INPUT_PULLUP);
  attachInterrupt(pinendstopYaw1,ISRendYaw1,CHANGE);
  
  pinMode(pinendstopYaw2,INPUT_PULLUP);
  attachInterrupt(pinendstopYaw2,ISRendYaw2,CHANGE);


if (digitalRead(pinendstopBase1)==HIGH){flagEndstopBase1prev==true;}
if (digitalRead(pinendstopBase1)==LOW){flagEndstopBase1prev==false;}


if (digitalRead(pinendstopBase2)==HIGH){flagEndstopBase2prev==true;}
if (digitalRead(pinendstopBase2)==LOW){flagEndstopBase2prev==false;}


if (digitalRead(pinendstopShoulder1)==HIGH){flagEndstopShoulder1prev==true;}
if (digitalRead(pinendstopShoulder1)==LOW){flagEndstopShoulder1prev==false;}


if (digitalRead(pinendstopShoulder2)==HIGH){flagEndstopShoulder2prev==true;}
if (digitalRead(pinendstopShoulder2)==LOW){flagEndstopShoulder2prev==false;}

  if (digitalRead(pinendstopElbow1)==HIGH){flagEndstopElbow1prev==true;}
if (digitalRead(pinendstopElbow1)==LOW){flagEndstopElbow1prev==false;}


  if (digitalRead(pinendstopElbow2)==HIGH){flagEndstopElbow2prev==true;}
if (digitalRead(pinendstopElbow2)==LOW){flagEndstopElbow2prev==false;}


  if (digitalRead(pinendstopRoll1)==HIGH){flagEndstopRoll1prev==true;}
if (digitalRead(pinendstopRoll1)==LOW){flagEndstopRoll1prev==false;}


  if (digitalRead(pinendstopRoll2)==HIGH){flagEndstopRoll2prev==true;}
if (digitalRead(pinendstopRoll2)==LOW){flagEndstopRoll2prev==false;}

  if (digitalRead(pinendstopPitch1)==HIGH){flagEndstopPitch1prev==true;}
if (digitalRead(pinendstopPitch1)==LOW){flagEndstopPitch1prev==false;}

  if (digitalRead(pinendstopPitch2)==HIGH){flagEndstopPitch2prev==true;}
if (digitalRead(pinendstopPitch2)==LOW){flagEndstopPitch2prev==false;}

  if (digitalRead(pinendstopYaw1)==HIGH){flagEndstopYaw1prev==true;}
if (digitalRead(pinendstopYaw1)==LOW){flagEndstopYaw1prev==false;}

  if (digitalRead(pinendstopYaw2)==HIGH){flagEndstopYaw2prev==true;}
if (digitalRead(pinendstopYaw2)==LOW){flagEndstopYaw2prev==false;}
}
 

void loop() {
    
  Read_From_Serial();
  Update_Time();
  Update_Motors();  
  Update_Encoders();
  Update_Battery();
  Update_Endstops();
}

///////////////////////////////////////////////////////////////////////////////////////////////////////////////////////////////////////////////////////////////////////////////////////
//Read from Serial Function

void Read_From_Serial()

{
   while(Serial.available() > 0)
    {
     
       int data = Serial.read();
       Messenger_Handler.process(data);
     
     
    } 
    
}





///////////////////////////////////////////////////////////////////////////////////////////////////////////////////////////////////////////////////////////////////////////////////////
//OnMssg Complete function definition

void OnMssageCompleted()
{
   
  char reset[] = "r";
  char set_speed[] = "s";
  
  if(Messenger_Handler.checkString(reset))
  {
    
     Serial.println("Reset Done"); 
     Reset();
    
  }
  if(Messenger_Handler.checkString(set_speed))
  {
    
     //This will set the speed
     Set_Speed();
     return; 
    
    
  }
}

//////////////////////////////////////////////////////////////////////////////////////////////////////////////////////////////////////////////////////////////////////////////////////
//Set speed
void Set_Speed()
{
    base_out=Messenger_Handler.readLong();
    shoulder_out=Messenger_Handler.readLong();
    elbow_out=Messenger_Handler.readLong();
    roll_out=Messenger_Handler.readLong();
    pitch_out=Messenger_Handler.readLong();
    yaw_out=Messenger_Handler.readLong();
    gripper_out=Messenger_Handler.readLong();
  //motor_left_speed = Messenger_Handler.readLong();
  //motor_right_speed = Messenger_Handler.readLong(); 

if(base_out>1500){base_stat=true;}
if(base_out<1500){base_stat=false;}
if(shoulder_out>64){shoulder_stat=true;}
if(shoulder_out<64){shoulder_stat=false;}
if(elbow_out>64){elbow_stat=true;}
if(elbow_out<64){elbow_stat=false;}
if(roll_out>64){roll_stat=true;}    
if(roll_out<64){roll_stat=false;}
if(pitch_out>64){pitch_stat=true;}    
if(pitch_out<64){pitch_stat=false;}
if(yaw_out>64){yaw_stat=true;}    
if(yaw_out<64){yaw_stat=false;}
}




void Reset()
{
  digitalWrite(GREEN_LED,HIGH);
  delay(1000);
  digitalWrite(RESET_PIN,LOW);
  digitalWrite(GREEN_LED,LOW);
}

void Update_Encoders()
{
  basel=encoder_digital(pindo1,pinclk1,pincsn1,&last_lec1,&vueltas1,&stat1);
  shoulder=encoder_digital(pindo2,pinclk2,pincsn2,&last_lec2,&vueltas2,&stat2);
  elbow=encoder_digital(pindo3,pinclk3,pincsn3,&last_lec3,&vueltas3,&stat3);
  displaySpeed_R2();
  set_status();
 // displaySpeed_Servo();
 Serial.print("e");
  Serial.print("\t");
  Serial.print(basel);
  Serial.print("\t");
  Serial.print(shoulder);
  Serial.print("\t");
  Serial.print(elbow);
  Serial.print("\t");
  Serial.print(roll);
  Serial.print("\t");
  Serial.print(pitch);
  Serial.print("\t");
  Serial.print(yaw);
  Serial.print("\n");
}



void displaySpeed_R2(void)
{
  uint8_t depth1,depth2,depth3,depth4;
  
  uint8_t status1,status2,status3,status4;
  bool valid1,valid2,valid3,valid4;
  int32_t enc3 = rc.ReadEncM1(address, &status1, &valid1);
  //int32_t speed1 = rc.ReadSpeedM1(address, &status2, &valid2);
  int32_t enc4 = rc.ReadEncM2(address, &status3, &valid3);
  //int32_t speed2 = rc.ReadSpeedM2(address, &status4, &valid4);
  float angulo3;
  float angulo4;
  if(valid1){//debe estar en radianes!!
  //angulo3=2*3.1416/2048*enc3;//conversion de ticks a radianes
  roll = enc3;
  }
  if(valid3){//debe estar en radianes!!
  //angulo4=2*3.1416/2048*enc4;//conversion de ticks a radianes
  pitch=enc4;
  }
}

void displaySpeed_Servo()
{
//return;
}

//////////////////////////////////////////////////////////////////////////////////////////////////////////
//Update motors function

void Update_Motors()
{
//BASE.write(base_out);
////////////////////////////////////////////////////////////////////////////////

if(flagEndstopBase1==true && flagEndstopBase2==false)
{
if(base_stat==true )
{if(base_out>1500){base.writeMicroseconds(base_out);}else {base.writeMicroseconds(1500);}}

if(base_stat==false)
{if(base_out<1500){base.writeMicroseconds(1500);}else {base.writeMicroseconds(base_out);}}
}

if(flagEndstopBase2==true && flagEndstopBase1==false)
{
if(base_stat==true)
{if(base_out>1500){base.writeMicroseconds(1500);}else {base.writeMicroseconds(base_out);}}

if(base_stat==false)
{if(base_out<1500){base.writeMicroseconds(base_out);}else {base.writeMicroseconds(1500);}}
}


if(flagEndstopBase1==false && flagEndstopBase2==false)
  base.writeMicroseconds(base_out);


///////////////////////////////////////////////////////////////////////////////

if (flagEndstopShoulder1==true)
{
if(shoulder_stat==false)
{if(shoulder_out<64){roboclaw.ForwardBackwardM1(address,shoulder_out);}else {roboclaw.ForwardBackwardM1(address,64);}}

if(shoulder_stat==true) //base
{if(shoulder_out>64){roboclaw.ForwardBackwardM1(address,64);}else {roboclaw.ForwardBackwardM1(address,shoulder_out);}}
}

if(flagEndstopShoulder2==true)
{
if(shoulder_stat==false)
{if(shoulder_out<64){roboclaw.ForwardBackwardM1(address,64);}else {roboclaw.ForwardBackwardM1(address,shoulder_out);}}

if(shoulder_stat==true)
{if(shoulder_out>64){roboclaw.ForwardBackwardM1(address,shoulder_out);}else {roboclaw.ForwardBackwardM1(address,64); }}
}
//roboclaw.ForwardBackwardM1(address,shoulder_out);
if(flagEndstopShoulder1==false && flagEndstopShoulder2==false )
roboclaw.ForwardBackwardM1(address,shoulder_out);  


///////////////////////////////////////////////////////////////////////////////

if (flagEndstopElbow1==true && flagEndstopElbow2==false)
{
if(elbow_stat==true)
{if(elbow_out<64){roboclaw.ForwardBackwardM2(address,elbow_out);}else {roboclaw.ForwardBackwardM2(address,64);}}

if(elbow_stat==false)
{if(elbow_out>64){roboclaw.ForwardBackwardM2(address,64);}else {roboclaw.ForwardBackwardM2(address,elbow_out);}}
}

if(flagEndstopElbow2==true && flagEndstopElbow1==false)
{
if(elbow_stat==true)
{if(elbow_out<64){roboclaw.ForwardBackwardM2(address,64);}else {roboclaw.ForwardBackwardM2(address,elbow_out);}}

if(elbow_stat==false)
{if(elbow_out>64){roboclaw.ForwardBackwardM2(address,elbow_out);}else {roboclaw.ForwardBackwardM2(address,64);}}
}
//roboclaw.ForwardBackwardM1(address,shoulder_out);
if(flagEndstopElbow1==false && flagEndstopElbow2==false )
roboclaw.ForwardBackwardM2(address,elbow_out);  


////////////////////////////////////////////////////////////////////////////////
if (flagEndstopRoll1==true && flagEndstopRoll2==false)
{
if(roll_stat==true)
{if(roll_out>64){rc.ForwardBackwardM1(address,64);}else {rc.ForwardBackwardM1(address,roll_out);}}

if(roll_stat==false)
{if(roll_out<64){rc.ForwardBackwardM1(address,roll_out);}else {rc.ForwardBackwardM1(address,64);}}
}

if(flagEndstopRoll2==true && flagEndstopRoll1==false)
{
if(roll_stat==true)
{if(roll_out>64){rc.ForwardBackwardM1(address,roll_out);}else {rc.ForwardBackwardM1(address,64);}}

if(roll_stat==false)
{if(roll_out<64){rc.ForwardBackwardM1(address,64);}else {rc.ForwardBackwardM1(address,roll_out);}}
}
//roboclaw.ForwardBackwardM1(address,shoulder_out);
if(flagEndstopRoll1==false && flagEndstopRoll2==false )
rc.ForwardBackwardM1(address,roll_out);  



//rc.ForwardBackwardM1(address,roll_out);

////////////////////////////////////////////////////////////////////////////////
if (flagEndstopYaw1==true && flagEndstopYaw2==false)
{
if(yaw_stat==true)
{if(yaw_out>64){rc.ForwardBackwardM2(address,yaw_out);}else {rc.ForwardBackwardM2(address,64);}}

if(yaw_stat==false)
{if(yaw_out<64){rc.ForwardBackwardM2(address,64);}else {rc.ForwardBackwardM2(address,yaw_out);}}
}

if(flagEndstopYaw2==true && flagEndstopYaw1==false)
{
if(yaw_stat==true)
{if(yaw_out>64){rc.ForwardBackwardM2(address,64);}else {rc.ForwardBackwardM1(address,yaw_out);}}

if(yaw_stat==false)
{if(yaw_out<64){rc.ForwardBackwardM2(address,yaw_out);}else {rc.ForwardBackwardM2(address,64);}}
}
//roboclaw.ForwardBackwardM1(address,shoulder_out);
if(flagEndstopYaw1==false && flagEndstopYaw2==false )
rc.ForwardBackwardM2(address,yaw_out);  



//rc.ForwardBackwardM2(address,pitch_out);
//TODO  agregar codigo del cytron correspondiente al yawXD

if (flagEndstopPitch1==true && flagEndstopPitch2==false)
{
if(pitch_stat==true)
{if(pitch_out>64){int pitch_temp=map(pitch_out,64,127,0,127); digitalWrite(pinCytronDir,LOW);analogWrite(pinCytronPwm,pitch_temp);}else {digitalWrite(pinCytronDir,HIGH);analogWrite(pinCytronPwm,0);}}

if(pitch_stat==false)
{if(pitch_out<64){digitalWrite(pinCytronDir,HIGH);analogWrite(pinCytronPwm,0);}}else {int pitch_temp=map(pitch_out,0,64,0,127); digitalWrite(pinCytronDir,HIGH);analogWrite(pinCytronPwm,pitch_temp);}
}

if(flagEndstopPitch2==true && flagEndstopPitch1==false)
{
if(pitch_stat==true)
{if(pitch_out>64) {digitalWrite(pinCytronDir,HIGH);analogWrite(pinCytronPwm,0);}  else {int pitch_temp=map(pitch_out,64,127,0,127); digitalWrite(pinCytronDir,HIGH);analogWrite(pinCytronPwm,pitch_temp);}}

if(pitch_stat==false)
{if(pitch_out<64) {int pitch_temp=map(pitch_out,0,64,0,127); digitalWrite(pinCytronDir,LOW);analogWrite(pinCytronPwm,pitch_temp);}  else {digitalWrite(pinCytronDir,HIGH);analogWrite(pinCytronPwm,0);}}
}
//roboclaw.ForwardBackwardM1(address,shoulder_out);
if(flagEndstopPitch1==false && flagEndstopPitch2==false )
{
 if(pitch_out>64){int pitch_temp=map(pitch_out,64,127,0,127); digitalWrite(pinCytronDir,HIGH);analogWrite(pinCytronPwm,pitch_temp);} 
 if(pitch_out<64){int pitch_temp=map(pitch_out,0,64,0,127); digitalWrite(pinCytronDir,LOW);analogWrite(pinCytronPwm,pitch_temp);}
 if(pitch_out==64){int pitch_temp=map(pitch_out,0,64,0,127); digitalWrite(pinCytronDir,LOW);analogWrite(pinCytronPwm,0);}    
}  


}
///////////////////////////////////////////////////////////////////////////////////////////////////////////////////////////////////////
///Update battery

void Update_Battery()
{
  uint16_t batt;
  bool validate;
  batt=rc.ReadMainBatteryVoltage(address, &validate);
  if(validate) battery=batt;
  Serial.print("b");
  Serial.print("\t");
  Serial.print(battery);
  Serial.print("\n");
}


////////////////////////////////////////////////////////////////////////////////////////////////////////////////////////////////////////////////////////////////////////////////////////
//Update time function
void Update_Time()
{
  CurrentMicrosecs = micros();
  LastUpdateMillisecs = millis();
  MicrosecsSinceLastUpdate = CurrentMicrosecs - LastUpdateMicrosecs;
  if (MicrosecsSinceLastUpdate < 0)
    {
  MicrosecsSinceLastUpdate = INT_MIN - LastUpdateMicrosecs + CurrentMicrosecs;

    }
  LastUpdateMicrosecs = CurrentMicrosecs;
  SecondsSinceLastUpdate = MicrosecsSinceLastUpdate / 1000000.0;

  Serial.print("t");
  Serial.print("\t");
  Serial.print(LastUpdateMicrosecs);
  Serial.print("\t");
  Serial.print(SecondsSinceLastUpdate);
  Serial.print("\n");
}

////////////////////////////////////////////////////////////////////////////////////////////////////////////////////////////////
/////Funcion para leer cada encoder pasando como valores de referencia 
int encoder_digital(int d0,int clk,int csn, unsigned int* last_lect,int* vueltas,boolean* statn)
{
int angle;
    digitalWrite(csn, LOW);
  delayMicroseconds(4);
    unsigned int data = 0;
  digitalWrite(clk, LOW);
  delayMicroseconds(1);
  for (uint8_t k = 0; k < 16; k++) 
    {
    digitalWrite(clk, HIGH);
    delayMicroseconds(1);
    data = (data << 1) | (digitalRead(d0) ? 0x0001 : 0x0000);
    digitalWrite(clk, LOW);
    delayMicroseconds(1);
     }


  digitalWrite(csn, HIGH);
  delayMicroseconds(1);
  digitalWrite(clk, HIGH);

//Condicionar la salida para que sea solo cuando es válido el valor del encoder
     if (!bitRead(data,3) && !bitRead(data,4) && bitRead(data,5) && !( bitRead(data,1) && bitRead(data,2) ))
     {
      *statn=true;

      if( abs((data>>6)-*last_lect) > 900 )
      {
              if((data>>6)>*last_lect)
                *vueltas-=1;
              else
                *vueltas+=1;     
      }
      else
      {*vueltas=*vueltas;}
        
     angle=(*vueltas)*(1023)+(data>>6) ;

     *last_lect=(data>>6);
     return (angle);
     }
     else
     {
      *statn=false;
      return(data>>6);
     }
}



void set_status()
{
  if(stat1)  bitWrite(stat_complete,0,1); else bitWrite(stat_complete,0,0);
  if(stat2)  bitWrite(stat_complete,1,1); else bitWrite(stat_complete,1,0);
  if(stat3)  bitWrite(stat_complete,2,1); else bitWrite(stat_complete,2,0);
}

///////////////////////////////////////////////////////////////////////////////////////////////////////////////////
///Funciones que imprime el estado de los endstops :)
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

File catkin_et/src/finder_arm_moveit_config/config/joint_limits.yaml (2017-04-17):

# joint_limits.yaml allows the dynamics properties specified in the URDF to be overwritten or augmented as needed
# Specific joint properties can be changed with the keys [max_position, min_position, max_velocity, max_acceleration]
# Joint limits can be turned off with [has_velocity_limits, has_acceleration_limits]
joint_limits:
  base_rotation:
    has_velocity_limits: true
    max_velocity: 0.1
    has_acceleration_limits: false
    max_acceleration: 0
  elbow_rotation:
    has_velocity_limits: true
    max_velocity: 0.1
    has_acceleration_limits: false
    max_acceleration: 0
  gripper_rotation:
    has_velocity_limits: true
    max_velocity: 0.1
    has_acceleration_limits: false
    max_acceleration: 0
  pitch_rotation:
    has_velocity_limits: true
    max_velocity: 0.1
    has_acceleration_limits: false
    max_acceleration: 0
  roll_rotation:
    has_velocity_limits: true
    max_velocity: 0.1
    has_acceleration_limits: false
    max_acceleration: 0
  roll_rotation_2:
    has_velocity_limits: true
    max_velocity: 0.1
    has_acceleration_limits: false
    max_acceleration: 0
  shoulder_rotation:
    has_velocity_limits: true
    max_velocity: 0.1
    has_acceleration_limits: false
    max_acceleration: 0

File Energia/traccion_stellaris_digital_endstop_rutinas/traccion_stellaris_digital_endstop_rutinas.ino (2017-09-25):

#include <Messenger.h>
#include <limits.h>
#include "RoboClaw.h"
#include "OSMC.h"
#include "AS5043.h"
#include "Encoder.h"

/////////////////////////////////////////////////////////////////////////////////////////////////////////
/*Estructura del programa
Define los objetos de lo OSMC, pines
Define los objetos asociados a los encoders, pines de prog, DO y CLK,
usamos rutinas de forma digital 
Define los encoders asigna pines analogicos, deberia de asignar tambien pines de seleccion clk y do
Defino variables de control de los motores
Defino variables de lectura de encoders
Defino roboclaws
SETUP //aqui quizas lo mas importante es fijarse que se inicien los objetos OSMC y los objetos de AS5043
definidos anteriormente
Loop
  Read from serial
  On_mssg_Completed
    llama a la siguiente funcion para leer los datos de entrafda desde ros psra asignar valores de pwm 
    a los osmc y roboclaw
  Set speed
    Descompone la cadena de entrada de datos en los valores a asignar a las variales de control de motores
  Reset
    Funcion de reset
  Update encoders
    LLamamos a la funcion read de cada objeto tipo encoder declarado, además se asignan pines de 
     lectura analógica para leer el voltaje de las baterias y la corriente de los motorees de traccion
  Update motors
    Mandamos los valores obtenidos en Set speed a las instrucciones de movimiento de los motores
  Update time
    Funcion de actualizacion de tiempo de ejecución

*//////////////////////////////////////////////////////////////////////////////////////////

/////////////////////////////////////////////////////////////////////////////////////////////
//DEfinimos los pines de los encoders

#define pindoIzq PA_6
#define pinclkIzq PA_7
#define pincsnIzq PE_3 

#define pindoDer PF_1
#define pinclkDer PF_3
#define pincsnDer PF_2 

#define pindo1 PD_2
#define pinclk1 PD_0
#define pincsn1 PD_1 

#define pindo2 PE_2
#define pinclk2 PD_3
#define pincsn2 PE_1 

#define pindo3 PC_4
#define pinclk3 PB_3
#define pincsn3 PC_5 

#define pindo4 PA_4
#define pinclk4 PA_3
#define pincsn4 PA_2 

#define endstop1 PE_5
#define endstop2 PF_0
#define endstop3 PF_4
#define endstop4 PE_0




///////////////////////////////////////////////////////////////////////////////////////////////////
//(pinpwm1,pinpwm2,umbral, maxpwmsense)
//OSMCClass LEFT(5,3,2,1,127);
//OSMCClass RIGHT(9,6,4,1,127);

//OSMCClass LEFT(PB_5,PB_0,PE_4,1,127);
//OSMCClass RIGHT(PB_1,PB_4,PA_5,1,127);

OSMCClass LEFT(PB_0,PB_5,PE_4,1,127);
OSMCClass RIGHT(PB_4,PB_1,PA_5,1,127);
//(clk,dO,pROG)
//(AS5043,CSn,input_min,input_max,output_max_abs_sense)
            
////////////////////////TODO agrgar los sensores de los flippers

Messenger Messenger_Handler=Messenger();
#define RESET_PIN PB_2

////////////////////////////
//Time update variables

unsigned long LastUpdateMicrosecs=0;
unsigned long LastUpdateMillisecs=0;
unsigned long CurrentMicrosecs=0;
unsigned long MicrosecsSinceLastUpdate=0;
float SecondsSinceLastUpdate=0;

///////////////////////////////////////////////////////////////
// Valores de control a los motores
int left_out=0;
int right_out=0;
int flipper1_out=64;
int flipper2_out=64;
int flipper3_out=64;
int flipper4_out=64;

///////////////////////////////////////////////////////////////////
//Variables de los encoders
int stat_complete=0;

int vueltasIzq;
unsigned int last_lecIzq;
boolean statIzq;

int vueltasDer;
unsigned int last_lecDer;
boolean statDer;

int vueltas1;
unsigned int last_lec1;
boolean stat1;
boolean fl1_stat;

int vueltas2;
unsigned int last_lec2;
boolean stat2;
boolean fl2_stat;

int vueltas3;
unsigned int last_lec3;
boolean stat3;
boolean fl3_stat;

int vueltas4;
unsigned int last_lec4;
boolean stat4;
boolean fl4_stat;

int left_lec=0;
int right_lec=0;
int flip1_lec=0;
int flip2_lec=0;
int flip3_lec=0;
int flip4_lec=0;

/////////////////////////////////////////////////////////////////////
//Agregar variables de la corriente de los motores y 
//de los finales de carrera, son dos de los motores y dos finales de carrera



bool endstp1;
bool endstp1prev;
bool endstp2;
bool endstp2prev;
bool endstp3;
bool endstp3prev;
bool endstp4;
bool endstp4prev;

//////////////////////////////////////////////////////////////////////
//Roboclaws
//Uncomment if Using Hardware Serial port
RoboClaw roboclaw(&Serial2,10000);
RoboClaw rc(&Serial3,10000);

#define address 0x80


void setup() {
Serial.begin(115200);//cuando se ve en el ide de arduino

  roboclaw.begin(38400);
  
  rc.begin(38400);
  
  SetupEncoders();
  
  SetupMotors();
  
  SetupReset();

  Messenger_Handler.attach(OnMssageCompleted);

  SetupEndstop();
}

void SetupEncoders()
{
pinMode(pinclkIzq,OUTPUT);
pinMode(pindoIzq,INPUT);
pinMode(pincsnIzq,OUTPUT);
digitalWrite(pincsnIzq,HIGH);
digitalWrite(pinclkIzq, HIGH);  
delay(100);

pinMode(pinclkDer,OUTPUT);
pinMode(pindoDer,INPUT);
pinMode(pincsnDer,OUTPUT);
digitalWrite(pincsnDer,HIGH);
digitalWrite(pinclkDer, HIGH);  
delay(100);

pinMode(pinclk1,OUTPUT);
pinMode(pindo1,INPUT);
pinMode(pincsn1,OUTPUT);
digitalWrite(pincsn1,HIGH);
digitalWrite(pinclk1, HIGH);  
delay(100);
pinMode(pinclk2,OUTPUT);
pinMode(pindo2,INPUT);
pinMode(pincsn2,OUTPUT);
digitalWrite(pincsn2,HIGH);
digitalWrite(pinclk2, HIGH);  
delay(100);
pinMode(pinclk3,OUTPUT);
pinMode(pindo3,INPUT);
pinMode(pincsn3,OUTPUT);
digitalWrite(pincsn3,HIGH);
digitalWrite(pinclk3, HIGH);  
delay(100);

pinMode(pinclk4,OUTPUT);
pinMode(pindo4,INPUT);
pinMode(pincsn4,OUTPUT);
digitalWrite(pincsn4,HIGH);
digitalWrite(pinclk4, HIGH);
delay(100);
  
}

void SetupMotors()
{
  pinMode(PE_4, OUTPUT);
  pinMode(PA_5, OUTPUT);
  LEFT.begin();
  RIGHT.begin();
}

void SetupReset()
{
  pinMode(GREEN_LED,OUTPUT);
  pinMode(RESET_PIN,OUTPUT);

  ///Conectar el pin de reset al pin reset de la placa
  digitalWrite(RESET_PIN,LOW);
}

void SetupEndstop()
{

  pinMode(endstop1,INPUT_PULLUP);

  attachInterrupt(endstop1,end1,CHANGE);

  
  pinMode(endstop2,INPUT_PULLUP);
  attachInterrupt(endstop2,end2,CHANGE);

  
  pinMode(endstop3,INPUT_PULLUP);


  attachInterrupt(endstop3,end3,CHANGE);
  
  pinMode(endstop4,INPUT_PULLUP);

  attachInterrupt(endstop4,end4,CHANGE);



if (digitalRead(endstop1)==HIGH){endstp1prev==true;}
if (digitalRead(endstop1)==LOW){endstp1prev==false;}

if (digitalRead(endstop2)==HIGH){endstp2prev==true;}
if (digitalRead(endstop2)==LOW){endstp2prev==false;}

if (digitalRead(endstop3)==HIGH){endstp3prev==true;}
if (digitalRead(endstop3)==LOW){endstp3prev==false;}

if (digitalRead(endstop4)==HIGH){endstp4prev==true;}
if (digitalRead(endstop4)==LOW){endstp4prev==false;}

}

 


void loop() {
    
  Read_From_Serial();
  Update_Time();
  Update_Motors();  
  Update_Encoders();
  Update_Endstops();
}

///////////////////////////////////////////////////////////////////////////////////////////////////////////////////////////////////////////////////////////////////////////////////////
//Read from Serial Function

void Read_From_Serial()
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

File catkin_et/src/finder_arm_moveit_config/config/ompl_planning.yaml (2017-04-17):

planner_configs:
  SBLkConfigDefault:
    type: geometric::SBL
    range: 0.0  # Max motion added to tree. ==> maxDistance_ default: 0.0, if 0.0, set on setup()
  ESTkConfigDefault:
    type: geometric::EST
    range: 0.0  # Max motion added to tree. ==> maxDistance_ default: 0.0, if 0.0 setup()
    goal_bias: 0.05  # When close to goal select goal, with this probability. default: 0.05
  LBKPIECEkConfigDefault:
    type: geometric::LBKPIECE
    range: 0.0  # Max motion added to tree. ==> maxDistance_ default: 0.0, if 0.0, set on setup()
    border_fraction: 0.9  # Fraction of time focused on boarder default: 0.9
    min_valid_path_fraction: 0.5  # Accept partially valid moves above fraction. default: 0.5
  BKPIECEkConfigDefault:
    type: geometric::BKPIECE
    range: 0.0  # Max motion added to tree. ==> maxDistance_ default: 0.0, if 0.0, set on setup()
    border_fraction: 0.9  # Fraction of time focused on boarder default: 0.9
    failed_expansion_score_factor: 0.5  # When extending motion fails, scale score by factor. default: 0.5
    min_valid_path_fraction: 0.5  # Accept partially valid moves above fraction. default: 0.5
  KPIECEkConfigDefault:
    type: geometric::KPIECE
    range: 0.0  # Max motion added to tree. ==> maxDistance_ default: 0.0, if 0.0, set on setup()
    goal_bias: 0.05  # When close to goal select goal, with this probability. default: 0.05 
    border_fraction: 0.9  # Fraction of time focused on boarder default: 0.9 (0.0,1.]
    failed_expansion_score_factor: 0.5  # When extending motion fails, scale score by factor. default: 0.5
    min_valid_path_fraction: 0.5  # Accept partially valid moves above fraction. default: 0.5
  RRTkConfigDefault:
    type: geometric::RRT
    range: 0.0  # Max motion added to tree. ==> maxDistance_ default: 0.0, if 0.0, set on setup()
    goal_bias: 0.05  # When close to goal select goal, with this probability? default: 0.05
  RRTConnectkConfigDefault:
    type: geometric::RRTConnect
    range: 0.0  # Max motion added to tree. ==> maxDistance_ default: 0.0, if 0.0, set on setup()
  RRTstarkConfigDefault:
    type: geometric::RRTstar
    range: 0.0  # Max motion added to tree. ==> maxDistance_ default: 0.0, if 0.0, set on setup()
    goal_bias: 0.05  # When close to goal select goal, with this probability? default: 0.05
    delay_collision_checking: 1  # Stop collision checking as soon as C-free parent found. default 1
  TRRTkConfigDefault:
    type: geometric::TRRT
    range: 0.0  # Max motion added to tree. ==> maxDistance_ default: 0.0, if 0.0, set on setup()
    goal_bias: 0.05  # When close to goal select goal, with this probability? default: 0.05
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

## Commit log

2017-02-24 agregar la carpeta de los programas usados para la roboclaw con arduino
2017-02-24 agregar carpeta de sketch para stellaris
2017-02-24 creacion de un workspace
2017-03-03 bibliotecas de jakob para stellaris
2017-03-08 usar el nuevo programa roboclaw encoder ros 1tarjeta
2017-03-09 agregue el archivo jointstate
2017-03-09 el archivo prueba_roboclaw_ros_1tarjeta es el bueno
2017-03-10 añadir el programa prueba roboclaw serialnode, funciona un poco mejor que el prueba roboclaw ros 1tarjeta, no usa rosserial, se corre con launchpadnodebrazo.py
2017-03-27 Readme tien instrucciones para usar el workspace
2017-04-07 cambie la velocidad de comunicacion a 38400
2017-04-07 modificque para que el control no haga cosas raras
2017-04-17 cambie jointstates
2017-04-17 Cesar agrego paquetes
    [base.obj, base.stl, brazo_der_frontal_v2.obj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]
2017-04-18 cambie la velocidad de la roboclaw de pitch y yaw a 38400
2017-04-18 en alunchpad del barzo le cambié el buffer de pitch y roll a 5
2017-04-18 agreue un .txt con valores de encoders para la regresion lineal
2017-04-19 modifique para funcionamiento conjunto con el joint_state _publisher del robot
2017-04-19 se modificaron valores en joint porque se movieron los imanes
2017-04-19 elimine un archivo que no necesitaba creo
2017-04-28 unicamente comenté el codigo
2017-04-28 Se agrego el documento Doc, es la documentacion del repositorio
2017-05-04 corregi un problema de codigo del encoder de la muñeca XD
    [prueba_roboclaw_serialnode.ino]
2017-05-04 agregure un programa de debuggeo para los encoders
2017-05-04 agregue a compilacion el joint state ṕublisher de debuggeo
2017-05-05 agregue traccion_stellaris, es el programa para la base
2017-05-06 agregue scripts de jakob
2017-05-09 agregue codigo a la stellaris de la base y al teleoperation
2017-05-09 teleoperation node
    [base.obj, brazo_der_frontal.obj, brazo_der_frontal.stl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]
2017-05-12 agregue el programa encoder_digital, es un programa simple para leer un solo encoder AS4053 de forma digital
2017-05-18 encoder_digital_algunos cambios, para lectura digital multivuelta
2017-05-20 programas encoder digital, con cuatro
2017-05-21 modfique .gitignore para quitar rosserial tivac
2017-05-26 reasignacion de oSMC
2017-05-29 se anadieron programas de prueba para el modo digital
2017-06-01 ligeras modificaciones, falta hacer el udev rules
2017-06-01 ya esta bien el programa de teleoperacion
2017-06-01 cambios en traccion digital para los encoders
2017-06-17 cosas de nacho
2017-06-18 se agregó restart de dynamixel y lectura de carga
2017-06-18 error de dedo corregido
2017-06-21 actualizacion de interfaz
2017-06-22 modifaciones de interface
2017-06-26 launch de la base
2017-06-26 launch de la base blabla
2017-06-27 Modificaciones de interface web, nuevo acomodo y barras de progreso
2017-06-28 se agrego el sensor de bateria en el programa del brazo.
2017-06-29 Cambios de cesat
    [finder.xacro]
2017-06-30 Script para instalar paquetes
2017-06-30 nuevo programa agregando finales de carrera
2017-06-30 publicadores en interface y mejora de launch
2017-06-30 endstops traccion digital endstops.ino
2017-06-30 endstops de la traccion
2017-06-30 Cambios de Eli
2017-06-30 nuevos cambios añadidos a endstops
2017-07-05 código de César
2017-07-05 Cambios en la interface - sensor termico
2017-07-07 se agregaron topicos de estado en la interface y se implemento el zbar detector
2017-07-07 lo que sea
2017-07-07 borre arduino
2017-07-12 codigo de cesar
2017-07-12 Sliders para Pan-Tilt en interface
2017-07-12 programa de traccion con endstpos
2017-07-12 Posiciones de juntas en interface
2017-07-13 cambios de gerardo durante tiempo de ejecucion
2017-07-13 Agregué código del termógrafo y sensor de co2
2017-07-14 cambios en teleoperation y se gregaron archivops finales de endstops
2017-07-14 finales de carrera ya funcionan bien
2017-07-14 correcion a topico de lectura estado de bateria del robot
2017-07-17 codigos de vision de Nacho
2017-07-26 marcas en el mapa actualizado
2017-07-26 cambios de ultima hora de vision e interface
2017-07-28 correcciones y cablibración de vision
2017-08-21 cambios ultimos a lo de las camaras , mavro
2017-08-25 se corrigieron programas de los endsatops y se hizo un launch completo en bring_pu launcWEBmono_mavro.launch
    [brazo_launchpad_digital_endstop_ruitnas.ino, traccion_stellaris_digital_endstop_rutinas.ino]
